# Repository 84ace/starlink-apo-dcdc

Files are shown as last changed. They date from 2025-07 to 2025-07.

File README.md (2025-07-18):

<h1 align="center">
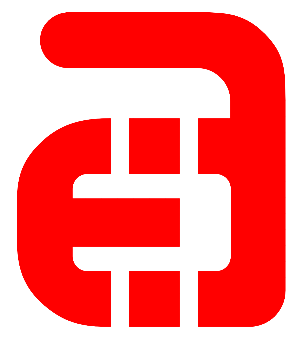
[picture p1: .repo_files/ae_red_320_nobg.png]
Ace's Electronics
    

  Ace's Electronics Pty Ltd  
  DC-DC converter for use in 12/24 volt systems
</h1>

# Looking to get up and running?
- [Wiki - Quickstart Guide](../../wiki/Quickstart-Guide)

# Project Goals:
The overall goal of this project is to make a simple, robust and reliable DC-DC converter for use in cars with smart alternators, such as the Next Gen Ranger and Everest. The DC-DC converter will be solid state and be able to handle input voltages in the range of 9-32V and output 25V 2.5A, or 62.5W.

# Design goals:  
- Smallest form-factor possible while being able to handle ~60W without getting too hot
- Can be used in-line with any cheap pass-through Starlink auxiliary 12V adapter
- Zero configuration
- Zero maintenance

# v0.0.1
Version 0.0.1 has been prototyped. I will hand assemble some test boards and do some testing. ~ETA for completion is 10/8/25.

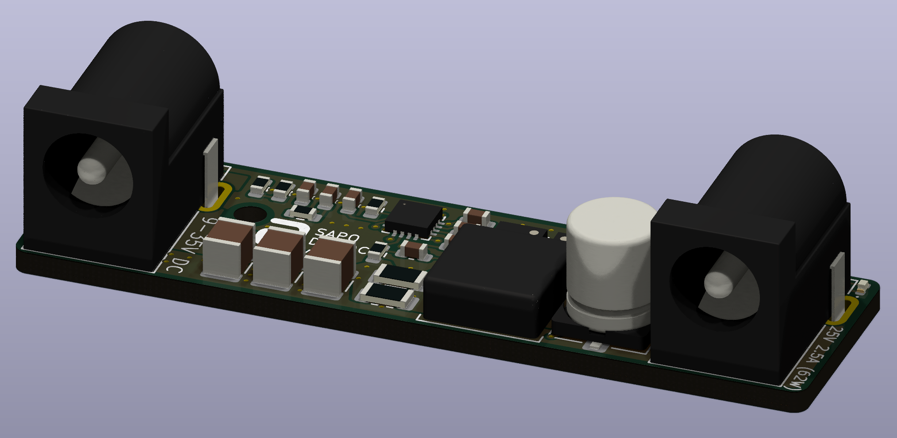
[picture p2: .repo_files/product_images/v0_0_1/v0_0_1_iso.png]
v0.0.1 PCB iso render

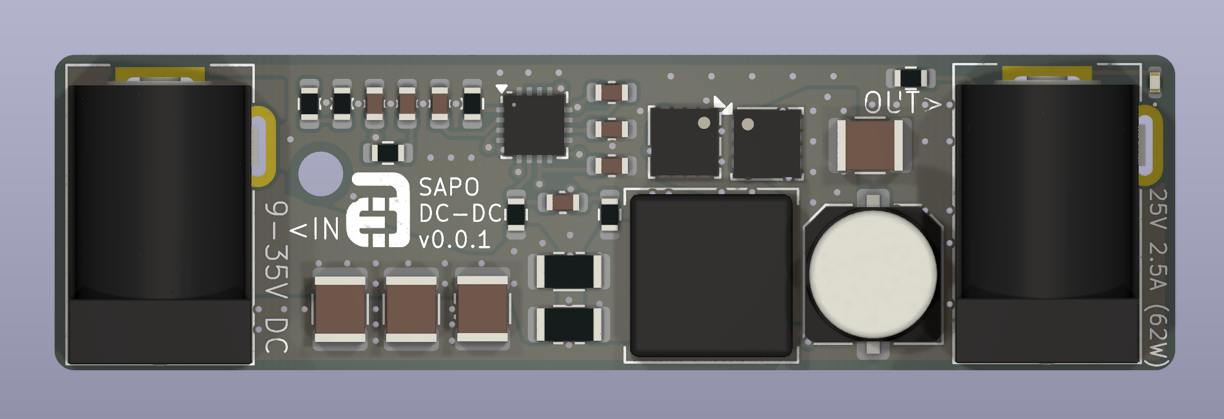
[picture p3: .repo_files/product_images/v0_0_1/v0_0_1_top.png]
v0.0.1 PCB top render

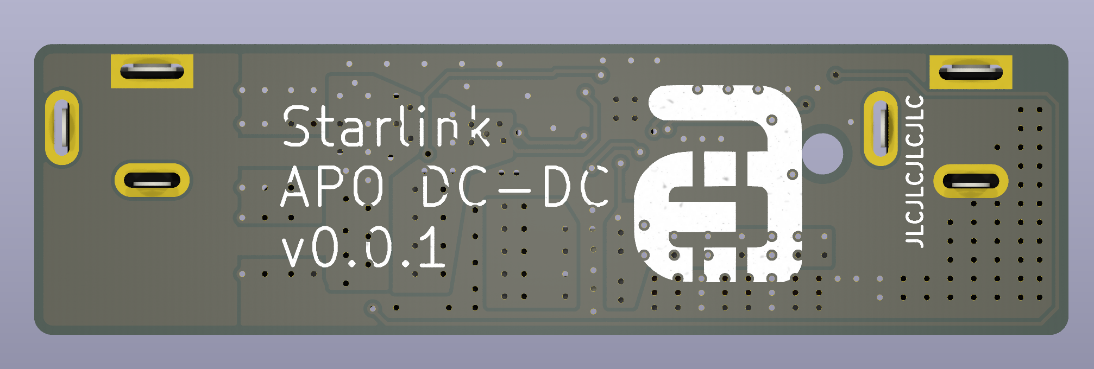
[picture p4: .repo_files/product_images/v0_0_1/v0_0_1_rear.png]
v0.0.1 PCB rear render

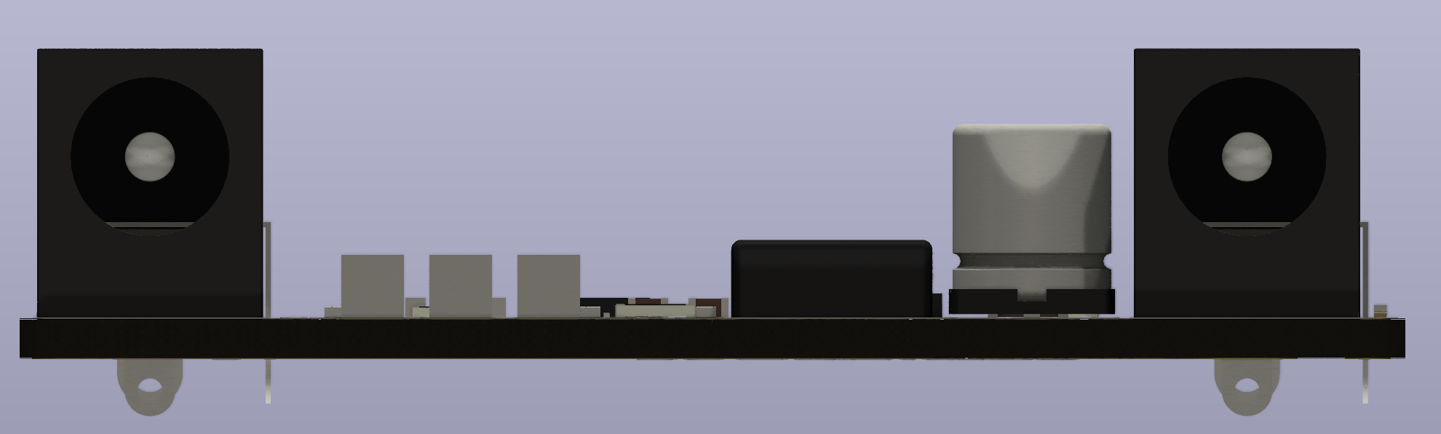
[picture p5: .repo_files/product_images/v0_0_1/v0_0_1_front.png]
v0.0.1 PCB front render


# Where to Buy:
TBA, but most likely will be vvailable to purchase in Australia or New Zealand via <a href="https://d1b959-f7.myshopify.com/">The AE Store</a>

## Support:
Contact me direct via ace<@>aceselectronics.com.au, just make it look like a normal email address. (hiding from the bots ;)

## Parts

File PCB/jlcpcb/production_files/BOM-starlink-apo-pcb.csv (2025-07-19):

Comment | Designator | Footprint | LCSC | Quantity
8mR | R3,R5 | R_1206_3216Metric | C1021507 | 2
10uF 50V | C4,C6,C7,C8 | C_1210_3225Metric | C138687 | 4
100nF | C2,C9 | C_0603_1608Metric | C14663 | 2
100pF | C1 | C_0603_1608Metric | C14858 | 1
2.2nF | C12 | C_0603_1608Metric | C1604 | 1
270pF | C11 | C_0603_1608Metric | C1608 | 1
4.7uH | L1 | L_Coilcraft_XAL7030-472 | C19191671 | 1
100R | R1,R2 | R_0603_1608Metric | C22775 | 2
6.19kR | R7 | R_0603_1608Metric | C228022 | 1
11kR | R6,R9 | R_0603_1608Metric | C25950 | 2
105kR | R8 | R_0603_1608Metric | C2933128 | 1
Barrel_Jack | J1,J2 | BarrelJack_Wuerth_6941xx301002 | C3096082 | 2
33uF 50V | C5 | C_Elec_6.3x7.7 | C402500 | 1
205kR | R4 | R_0603_1608Metric | C5126104 | 1
TPS43061RTE | U1 | WQFN-16-1EP_3x3mm_P0.5mm_EP1.6x1.6mm_ThermalVias | C527683 | 1
4.7nF | C13 | C_0603_1608Metric | C53987 | 1
LED_Small | D1 | LED_0402_1005Metric | C779449 | 1
CSD16327Q3 | Q1,Q2 | VSON-8_3.3x3.3mm_P0.65mm_NexFET | C840100 | 2
10uF | C10 | C_0603_1608Metric | C96446 | 1

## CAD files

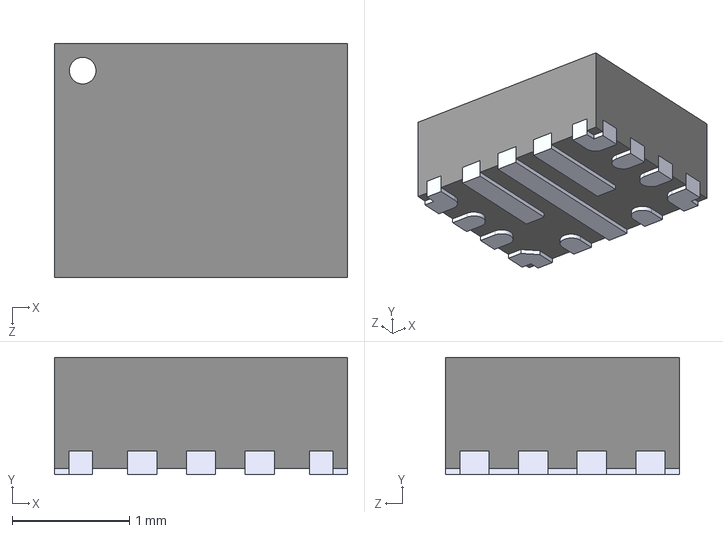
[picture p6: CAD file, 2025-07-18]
PCB/footprints/TPS61376RYHR/TPS61376RYHR.step
2.50 x 1.00 x 2.00 mm

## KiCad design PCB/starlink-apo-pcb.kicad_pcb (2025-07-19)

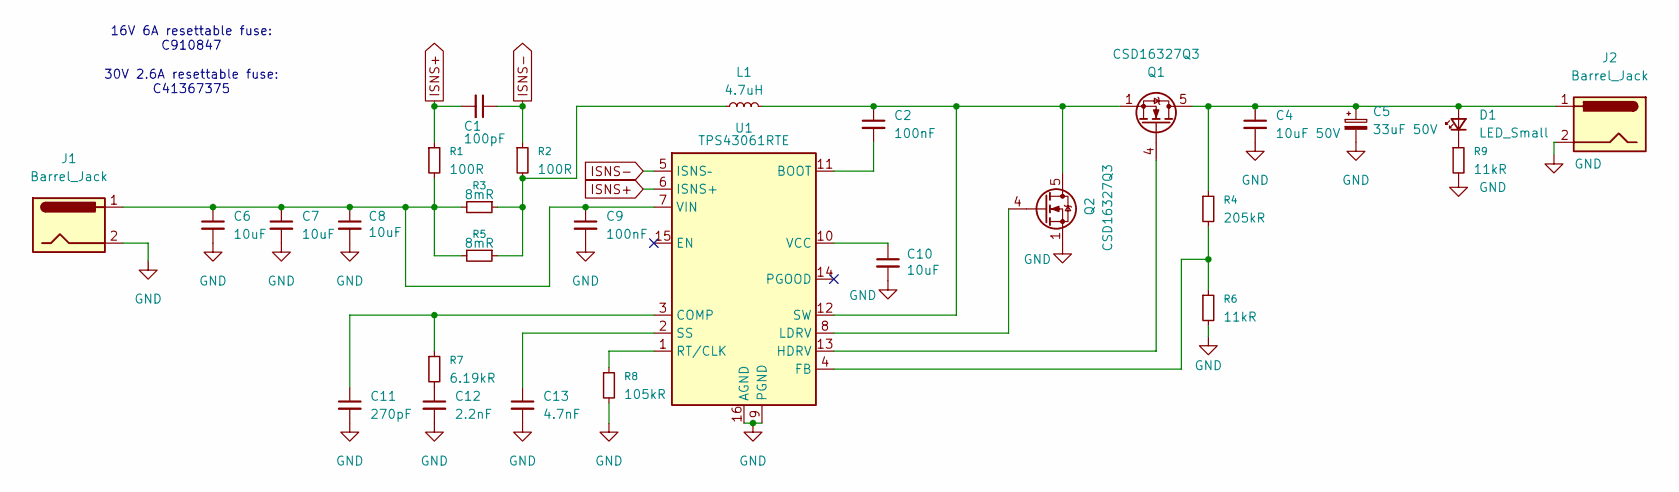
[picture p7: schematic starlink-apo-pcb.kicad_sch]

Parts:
C1: 100pF; C_0603_1608Metric; lcsc C14858
C2, C9: 100nF; C_0603_1608Metric; lcsc C14663
C4: 10uF 50V; C_1210_3225Metric; lcsc C138687
C5: 33uF 50V; C_Elec_6.3x7.7; lcsc C402500
C6, C7, C8: 10uF; C_1210_3225Metric; lcsc C138687
C10: 10uF; C_0603_1608Metric; lcsc C96446
C11: 270pF; C_0603_1608Metric; lcsc C1608
C12: 2.2nF; C_0603_1608Metric; lcsc C107082
C13: 4.7nF; C_0603_1608Metric; lcsc C597215
D1: LED_Small; LED_0402_1005Metric; lcsc C779449
J1, J2: Barrel_Jack; BarrelJack_Wuerth_6941xx301002; lcsc C3096082
L1: 4.7uH; L_Coilcraft_XAL7030-472; lcsc C19191671
Q1, Q2: CSD16327Q3; VSON-8_3.3x3.3mm_P0.65mm_NexFET; lcsc C840100
R1, R2: 100R; R_0603_1608Metric; lcsc C105588
R3, R5: 8mR; R_1206_3216Metric; lcsc C1021507
R4: 205kR; R_0603_1608Metric; lcsc C861745
R6, R9: 11kR; R_0603_1608Metric; lcsc C473242
R7: 6.19kR; R_0603_1608Metric; lcsc C228022
R8: 105kR; R_0603_1608Metric; lcsc C2933128
U1: TPS43061RTE; WQFN-16-1EP_3x3mm_P0.5mm_EP1.6x1.6mm_ThermalVias; lcsc C527683

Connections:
GND: C4.2, C5.2, C6.2, C7.2, C8.2, C9.2, C10.2, C11.2, C12.2, C13.2, J1.2, J2.2, Q2.1 (S), Q2.2 (S), Q2.3 (S), R6.2, R8.2, R9.2, U1.9 (PGND), U1.16 (AGND), U1.17 (AGND)
ISNS+: C1.2, R1.1, U1.6 (ISNS+)
ISNS-: C1.1, R2.1, U1.5 (ISNS–)
unnamed: C12.1, R7.2
unnamed: C4.1, C5.1, D1.2 (A), J2.1, Q1.5 (D), R4.1
unnamed: D1.1 (K), R9.1
unnamed: L1.1, R2.2, R3.1, R5.1
unnamed: Q1.4 (G), U1.13 (HDRV)
unnamed: C2.1, L1.2, Q1.1 (S), Q1.2 (S), Q1.3 (S), Q2.5 (D), U1.12 (SW)
unnamed: Q2.4 (G), U1.8 (LDRV)
unnamed: C2.2, U1.11 (BOOT)
unnamed: C11.1, R7.1, U1.3 (COMP)
unnamed: R4.2, R6.1, U1.4 (FB)
unnamed: R8.1, U1.1 (RT/CLK)
unnamed: C13.1, U1.2 (SS)
unnamed: C10.1, U1.10 (VCC)
unnamed: C6.1, C7.1, C8.1, C9.1, J1.1, R1.2, R3.2, R5.2, U1.7 (VIN)

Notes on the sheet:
16V 6A resettable fuse: C910847 30V 2.6A resettable fuse: C41367375

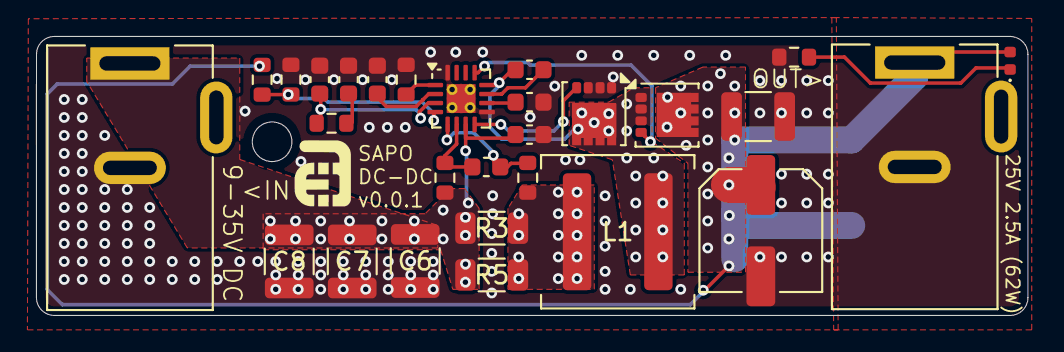
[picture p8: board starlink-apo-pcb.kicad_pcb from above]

Board: 2 copper layers, 55.1 x 15.5 mm, 28 parts (0 on the bottom side), 17 nets.

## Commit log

2025-07-18 setting up repo
    [TPS61376RYHR.step, starlink-apo-pcb.kicad_pcb, starlink-apo-pcb.kicad_sch]
2025-07-19 v0.0.1 off to JLCPCB
    [BOM-starlink-apo-pcb.csv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]
